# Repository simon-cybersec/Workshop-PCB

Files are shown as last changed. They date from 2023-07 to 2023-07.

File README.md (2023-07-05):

# Workshop-PCB

A nice little PCB for a soldering workshop I've done in the past. It has a mikrocontroller, a little OLED-display, a button, a LED and some SMD parts. \
When the button is pressed the display shows a text and the LED blinks, both for a time duration of ten minutes. The PCB is powered by a CR2032 coin cell battery.  

image of the PCB

# The PCB design

The PCB is designed in order to be challenging but also to be fun to solder. Therefore the parts are surface mounted (SMD parts) with a size of 0805 which is kind of small, but not too small ;)  
 - The mikrocontroller is a [_STM32L062K8_](https://www.st.com/en/microcontrollers-microprocessors/stm32l062k8.html) from ST Microelectronics in a 32 pin LQFP package.

 - The OLED-display is bought from Amazon and is 1.3 inch in size. It communicates with the uC using the I2C protocol. The display is mounted on the main PCB with four screws.

 - For the processor clock an external crystal is used. It clocks with 8 MHz.  

 - Button debouncing is done in software in order to keep the PCB simple and because the workshop time was limited.  

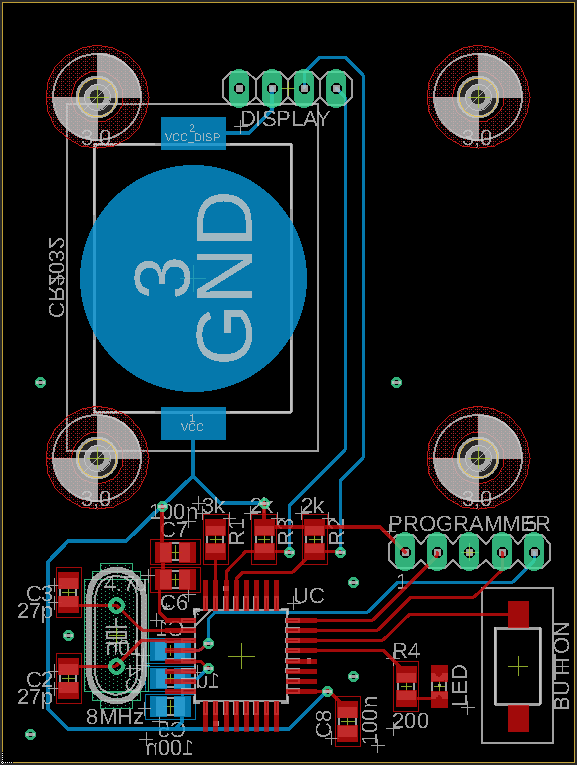
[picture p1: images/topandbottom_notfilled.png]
image of the PCB
  
  
# The parts

- Mikrocontroller \
[_STM32L062K8_](https://www.st.com/en/microcontrollers-microprocessors/stm32l062k8.html) (LQFP32 package)

- Button \
[_PTS636 SL43 SMTR LFS_](https://www.mouser.de/ProductDetail/CK/PTS636-SL43-SMTR-LFS?qs=vLWxofP3U2x0maTON%2FqK1g%3D%3D)

- Crystal \
[_ECS-80-18-4X-CKM_](https://www.mouser.de/ProductDetail/ECS/ECS-80-18-4X-CKM?qs=7MVldsJ5UazWVU6%2F43NmVA%3D%3D)

- 1.3 inch OLED display \
[_Link to Amazon_](https://www.amazon.de/AZDelivery-Display-Arduino-Raspberry-Gratis/dp/B078J78R45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)

- SMD LED \
[LG R971-KN-1](https://www.mouser.de/ProductDetail/ams-OSRAM/LG-R971-KN-1?qs=LsPilcdHE7EX1EB7GCLHxg%3D%3D) (size 0805)

- SMD capacitors and resistors (see down below)

- Pin header

- Coin battery _CR2032_

- SMD coin battery holder 

- screws and screw nuts (4x)
 
#### Capacitors (size 0805)
| Part | Value |
|---|---|
| C1 | 10n |
| C2 | 27p |
| C3 | 27p |
| C4 | 1u |
| C5 | 100n  |
| C6 | 4.7u  |
| C7 | 100n  |
| C8 | 100n  |  

#### Resistors (size 0805)
| Part | Value |
|---|---|
| R1 | 3k |
| R2 | 2k |
| R3 | 2k |
| R4 | 200 |

# Eagle files
The files are located in the folder "_eagle-files_".  

# How to flash the uC
In order to flash the uC the _serial wire debug_ (SWD) protocol is used. The corresponding pins of the uC are layouted to the PCBs pinheader (have a look at the eagle files). I used a NUCLEO-development-board from ST, which is not only able to flash its own uC but also can flash external ones.  

# Note
Also have a look at my blog [simon-cybersec.github.io](https://simon-cybersec.github.io) which is all about embedded systems, cybersecurity and other crazy stuff ;)

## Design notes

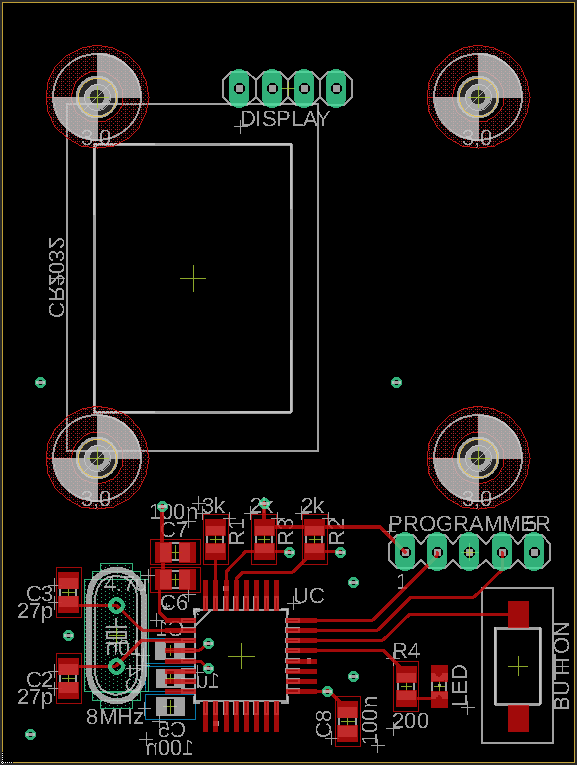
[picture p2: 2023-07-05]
images/top_notfilled.png

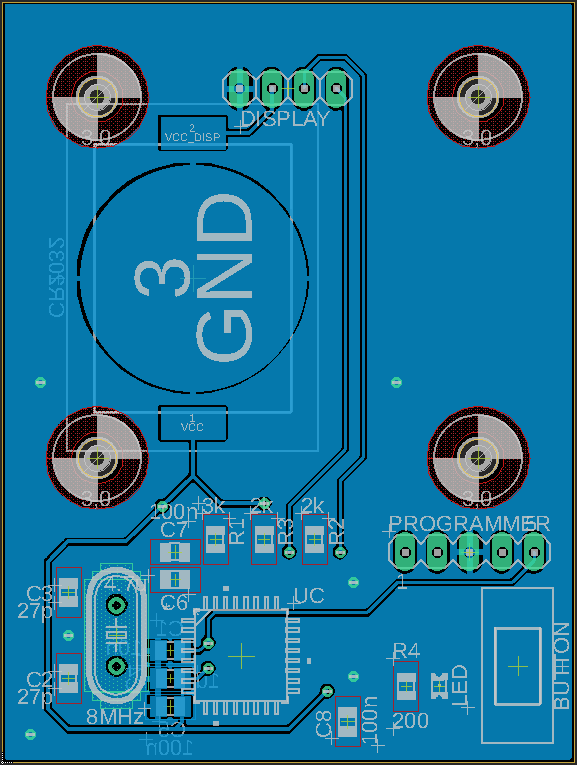
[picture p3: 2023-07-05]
images/bottom_filled.png

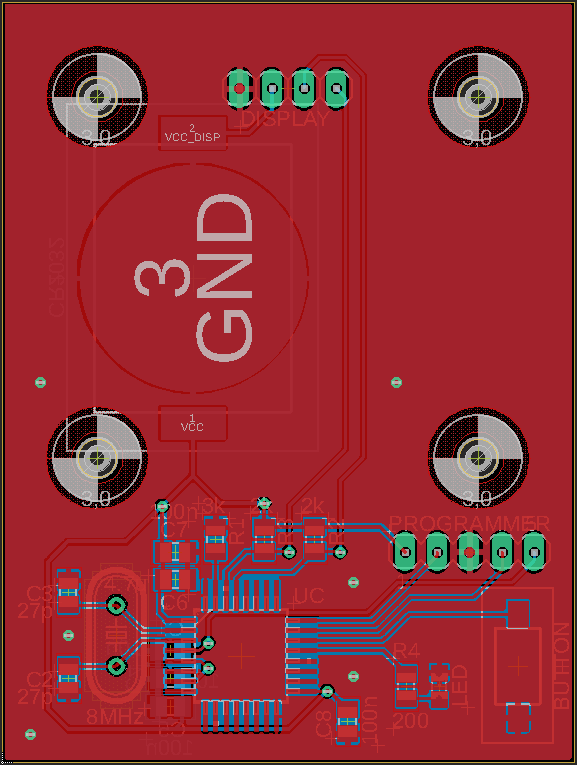
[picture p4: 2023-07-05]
images/topandbottom_filled.png

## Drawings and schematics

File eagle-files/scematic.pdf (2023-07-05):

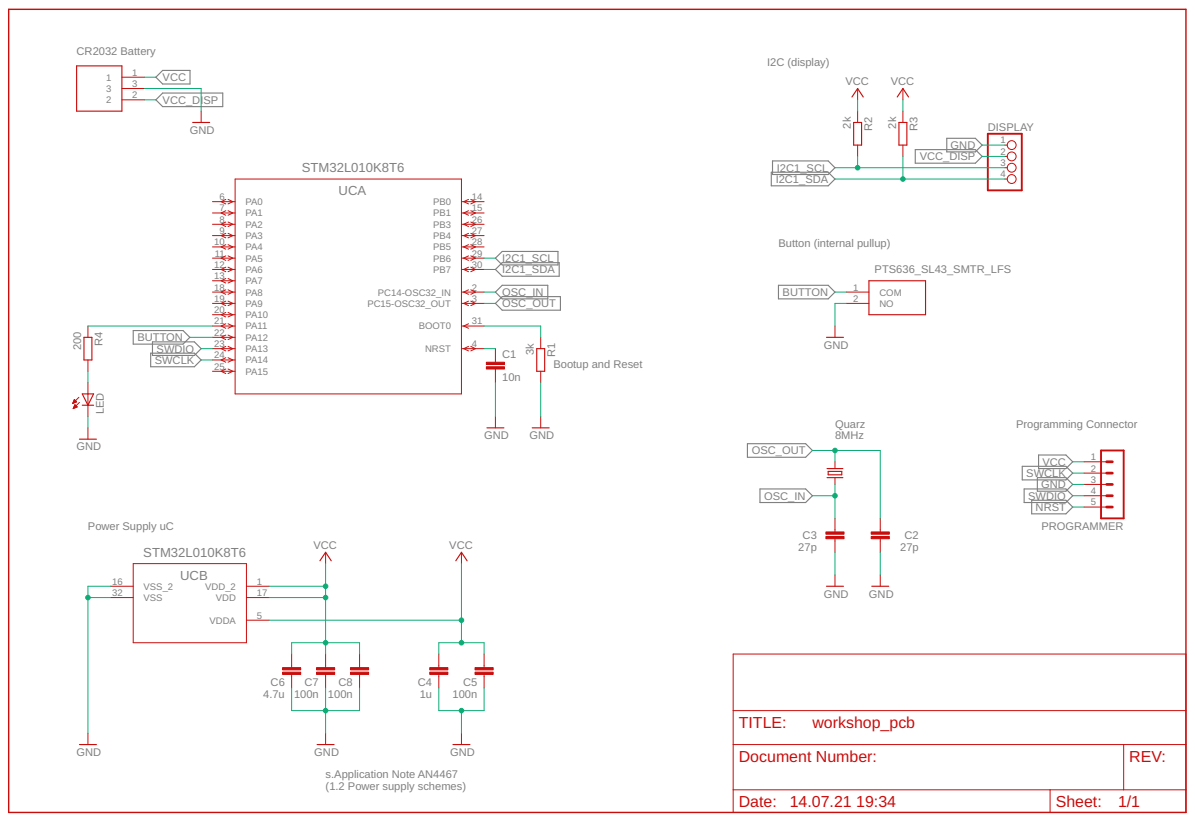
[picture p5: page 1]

Document Number: | REV:

Date: 14.07.21 19:34 | Sheet: 1/1

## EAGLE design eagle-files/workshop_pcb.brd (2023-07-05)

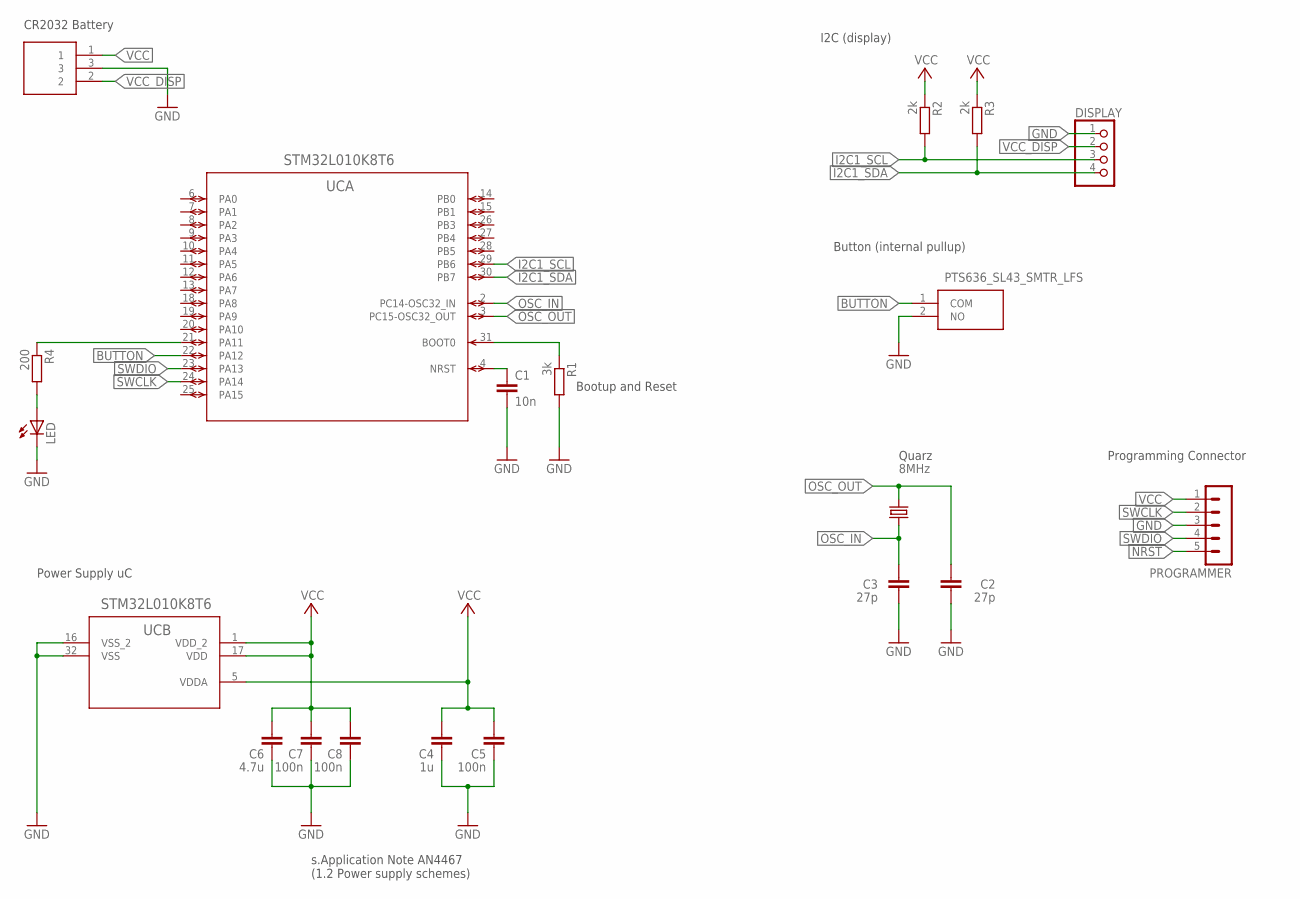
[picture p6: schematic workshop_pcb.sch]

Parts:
BUTTON: PTS636_SL43_SMTR_LFS; PTS636SL43SMTRLFS
C1: 10n; C0805
C2, C3: 27p; C0805
C4: 1u; C0805
C5, C7, C8: 100n; C0805
C6: 4.7u; C0805
CR2032: BAT-HLD-001; BATHLD001
DISPLAY: PINHD-1X4; 1X04
LED: LEDCHIPLED_0805; CHIPLED_0805
PROGRAMMER: MA05-1
QUARZ: 8MHz; HC49/S
R1: 3k; R0805
R2, R3: 2k; R0805
R4: 200; R0805
UC: STM32L010K8T6; LQFP32_7X7X1P4

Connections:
BOOT0: R1.1, UC.31 (BOOT0)
BUTTON: BUTTON.1 (COM), UC.22 (PA12)
GND: BUTTON.2 (NO), C1.2, C2.1, C3.1, C4.1, C5.1, C6.1, C7.1, C8.1, CR2032.3, DISPLAY.1, LED.C, PROGRAMMER.3, R1.2, UC.16 (VSS_2), UC.32 (VSS)
I2C1_SCL: DISPLAY.3, R2.2, UC.29 (PB6)
I2C1_SDA: DISPLAY.4, R3.2, UC.30 (PB7)
unnamed: LED.A, R4.2
unnamed: R4.1, UC.21 (PA11)
NRST: C1.1, PROGRAMMER.5, UC.4 (NRST)
OSC_IN: C3.2, QUARZ.2, UC.2 (PC14-OSC32_IN)
OSC_OUT: C2.2, QUARZ.1, UC.3 (PC15-OSC32_OUT)
SWCLK: PROGRAMMER.2, UC.24 (PA14)
SWDIO: PROGRAMMER.4, UC.23 (PA13)
VCC: C4.2, C5.2, C6.2, C7.2, C8.2, CR2032.1, PROGRAMMER.1, R2.1, R3.1, UC.1 (VDD_2), UC.5 (VDDA), UC.17 (VDD)
VCC_DISP: CR2032.2, DISPLAY.2

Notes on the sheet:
Bootup and Reset
Quarz
Power Supply uC
I2C (display)
Programming Connector
CR2032 Battery
s.Application Note AN4467 (1.2 Power supply schemes)
Button (internal pullup)

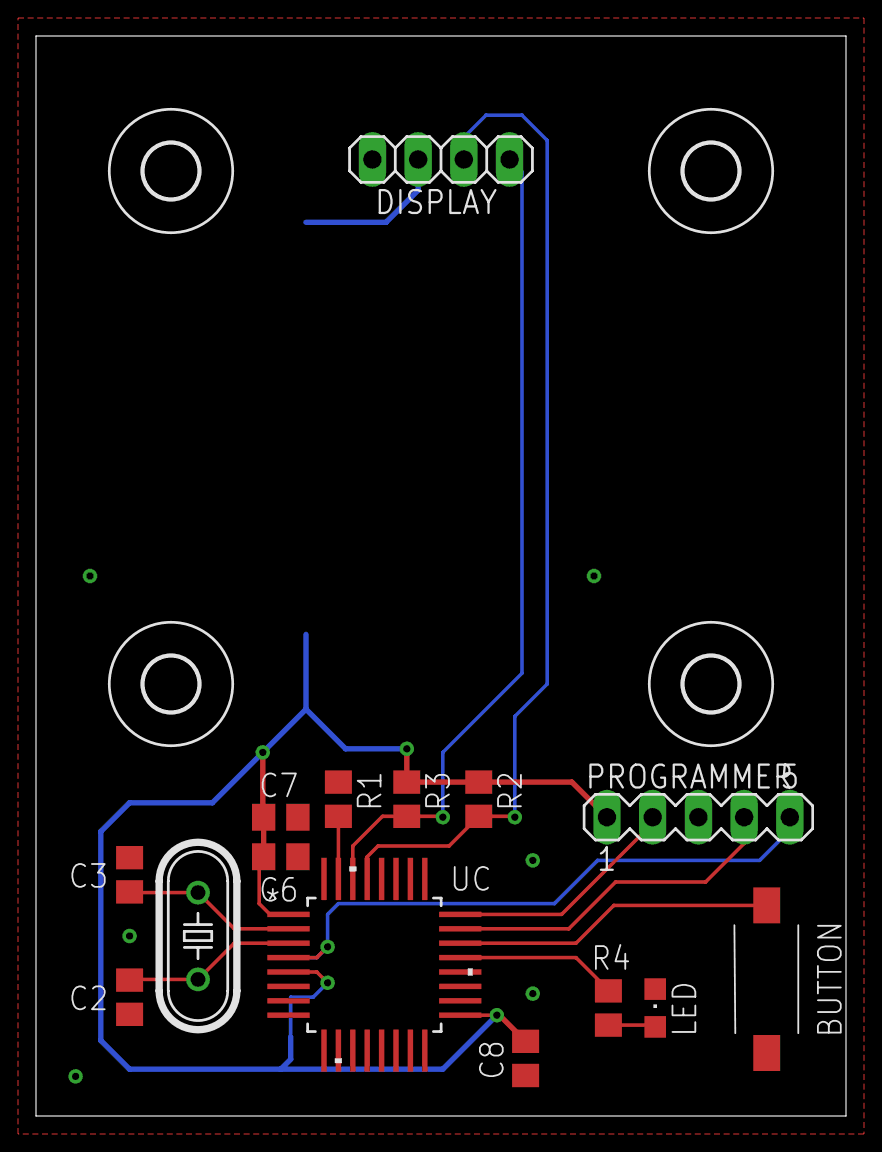
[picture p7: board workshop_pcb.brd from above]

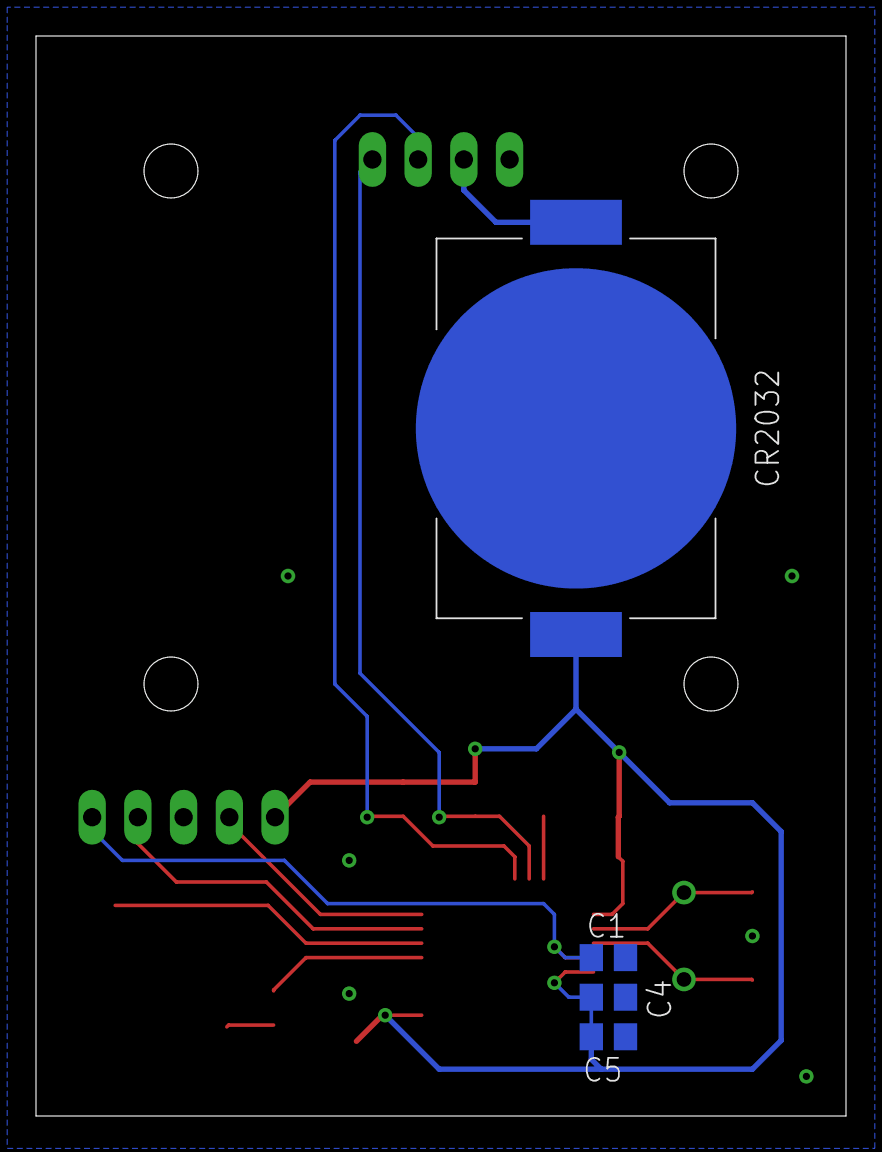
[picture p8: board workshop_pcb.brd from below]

Board: 2 copper layers, 45.0 x 60.0 mm, 23 parts (4 on the bottom side), 14 nets.

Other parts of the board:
U$1, U$2, U$3, U$4: 3,0

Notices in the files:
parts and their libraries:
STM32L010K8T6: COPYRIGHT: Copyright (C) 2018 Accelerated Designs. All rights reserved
